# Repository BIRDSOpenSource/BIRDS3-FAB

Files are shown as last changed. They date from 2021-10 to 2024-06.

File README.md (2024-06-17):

<p align="center">
<a href="https://lean-sat.org/opensource/" class="button icon calendar">Join Monthly Webinar</a>
</p>

<div align="center">

</div>

# BIRDS3-FAB
 Documentation for the Foward Access Board used in the BIRDS 3 Satellite

## About the BIRDS3 Program:



The project was led by Kyushu Institute of Technology in Japan and involves students from Sri Lanka, Bhutan, Nepal and Japan.
Satellite Names: NepaliSat-1 (Nepal), Raavana-1 (Sri Lanka) and Ugiusu (Japan)

Stakeholders: Nepal Academy of Science and Technology (NAST) for Nepal, Arthur C Clarke Institute for Modern Technologies (ACCIMT) for Sri Lanka, and Kyushu Institute of Technology (Kyutech) for Japan.

Project duration: 2018-2020

CubeSat: 1U (10x10x10) cm3

Weight: 1.13kg

Launch Date: 17th April 2019

BIRDS-3 has 4 main missions in total; LoRa Demonstration Mission (LDM), Imaging Mission (CAM), Attitude Determination and Control Mission (ADCS) and Software Configurable Backplane Mission (BPB) 

## Organisation structure

## Features

## I like this project, can I help you?
You are welcome 🙂

* Give us a star ⭐
* Watch repository to be notified about updates 👀
* If you will find some errors, report them in Issues 🐞
* Try Birds designs on some real computer and let us know how it worked in Discussions. 💬
* We would greatly appreciate if you would also tell others about this ecosystem, it helps us to improve BIRDS Open Source. Thank you!

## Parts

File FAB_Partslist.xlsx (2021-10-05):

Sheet: Birds3_FAB
BIRDS3 FAB ADC & Connectors Revised: Tuesday, January 16, 2018
B3_0001-1-6 Revision: 0.16
Item | Quantity | Reference | Part
Item | Quantity | Reference | Part | メーカー | 型番 | パッケージ | 動作温度 | 偏差 | 定格 | データシート
1 | 1 | CN301 | 2row-50pin pin socket | 本多通信工業 | LPC-50M2LG | 2.00mmピッチ50pin | -25℃～85℃ |  | 1A
2 | 1 | CN303 | CONN SOCKET 10 | JST | B10B-PASK-1 (LF) (SN) | 2.00mmピッチ10pin | -25℃～85℃ |  | 3A
3 | 1 | CN304 | CONN SOCKET 4 | JST | B04B-PASK-1 (LF) (SN) | 2.00mmピッチ4pin | -25℃～85℃ |  | 3A
4 | 1 | CN401 | CONN SOCKET 12 | 廣杉計器 | PSR-210154-12 | 2.00mmピッチ12pin ライトアングル | -40℃～105℃ |  | 2A
5 | 4 | C1,C4,C28,C33 | 10uF | 村田製作所 | GRM21BR71A106KE51L | 2012 | -55℃～125℃ | ±10% | 10V
6 | 1 | C2 | 1uF | 村田製作所 | GRM188R71C105KA12J | 1608 | -55℃～125℃ | ±10% | 16V
7 | 21 | C3,C5,C6,C12,C17,C18,C19, C20,C21,C22,C23,C24,C25, C26,C27,C29,C30,C31,C32, C41,C42 | 0.1uF | KEMET | C0603C104J4RACTU | 1608 | -55℃～125℃ | ±5% | 16V
8 | 1 | C7 | 4700pF | TDK | C1608C0G1E472J080AA |  | -55℃～125℃ | ±5% | 25V
9 | 1 | C8 | 620pF | 村田製作所 | GRM1885C1H621JA01D | 1608 | -55°C～125°C | ±5% | 100V
10 | 2 | C11,C40 | 4.7uF | 村田製作所 | GRM188C71A475KE11D | 1608 | -55℃～125℃ | ±10% | 10V
11 | 6 | C9,C10,C13,C14,C15,C16 | 100uF | 村田製作所 | GRM32EC70J107ME15L | 3225 | -55℃～125℃ | ±20% | 6.3V
12 | 1 | C36 | 22uF | 村田製作所 | GRM21BD71A226ME44L | 2012 | -55℃～125℃ | ±20% | 10V
13 | 1 | D1 | DFLS2100 | DIODES | DFLS2100Q-7 | PowerDI123 | -55℃～175℃ |  | 2A
14 | 1 | D2 | BAS40-05W | NXP | BAS40-05W | 2.2x1.35 | -65℃～150℃
15 | 1 | J1 | Socket 4x2 | Samtec | SFMC-104-01-S-D | 1.27mm | -55℃ ～ 125℃
16 | 3 | J2,J4,J5 | Socket 2x2 | Samtec | SFMC-102-01-S-D | 1.27mm | -55℃ ～ 125℃
17 | 1 | J3 | Socket 5x2 | Samtec | SFMC-105-01-S-D | 1.27mm | -55℃ ～ 125℃
18 | 1 | J6 | CONN SOCKET 3x2/SM | Samtec | CLM-103-02-F-D | 1mm ピッチ | -55℃ ～ 125℃
19 | 6 | J7,J8,J13,J14,J15,J16 | JUMPER 2 | MAC8 | HWC-2P-G | 2mm SMT | －40～＋125℃ |  | 3A
20 | 2 | J9,J10 | pin header 2x2 | Amphenol FCI | 10112690-G03-02LF | 2mm SMT Right Angle | -55°C ~ 125°C |  | 2A | * RBF子基板
21 | 2 | J11,J12 | PHONOJACK STEREO-15 | CUI-inc | SJ1-2535-SMT |  | -25°C～85°C |  | 1A | * RBF子基板
22 | 1 | L1 | 3.3uH | Murata | FDVE1040-H-3R3M=P3 | 11.2mmx10mm | -20〜100℃ |  | 9A
23 | 8 | Q1,Q2,Q3,Q4,Q5,Q6,Q7,Q8 | SiA447DJ | Vishay | SiA447DJ-T1-GE3 | SC-70-6L | -55℃～150℃
24 | 2 | Q9,Q10 | DTR_PNP | Nexperia | PDTA144EU,115 | SOT-323-3
25 | 1 | Q11 | SSM6K411TU | TOSHIBA | SSM6K411TU | UF6 | -55℃～150℃
26 | 19 | R1,R2,R3,R23,R25,R28,R30, R33,R35,R37,R39,R49,R64, R67,R68,R74,R75,R76,R81 | 1K | KOA | RK73B1JTTD102J | 1608 | -55℃～155℃ | ±5% | 0.1W
27 | 15 | R4,R5,R6,R7,R8,R9,R10, R11,R53,R55,R58,R60,R61, R62,R63 | F10K | KOA | RK73H1JTTD1002F | 1608 | -55℃～155℃ | ±1% | 0.1W
28 | 5 | R12,R48,R54,R57,R85 | 10K | KOA | RK73B1JTTD103J | 1608 | -55℃～155℃ | ±5% | 0.1W
29 | 2 | R13,R17 | F100K | KOA | RK73H1JTTD1003F | 1608 | -55℃～155℃ | ±1% | 0.1W
30 | 1 | R14 | 7.5K | KOA | RK73H1JTTD7501F | 1608 | -55℃～155℃ | ±1% | 0.1W
31 | 1 | R15 | F105K | Yageo | RC0603FR-07105KL | 1608 | -55℃～155℃ | ±1% | 0.1W
32 | 1 | R16 | F64.9K | Yageo | RT0603BRD0764K9L | 1608 | -55℃～155℃ | ±1% | 0.1W
33 | 3 | R18,R51,R84 | NM1608 |  |  | 1608
34 | 2 | R19,R21 | F430K | KOA | RK73H1JTTD4303F | 1608 | -55℃～155℃ | ±1% | 0.1W
35 | 15 | R20,R22,R24,R26,R27,R29, R32,R34,R36,R38,R56,R78, R80,R82,R83 | 100K | KOA | RK73B1JTTD104J | 1608 | -55℃～155℃ | ±5% | 0.1W
36 | 6 | R31,R40,R47,R50,R52,R59 | F0.050 | Panasonic | ERJ-L03KF50MV | 1608 | -55℃～155℃ | ±1% | 0.2W
37 | 6 | R41,R42,R43,R44,R45,R46 | 100 | KOA | RK73B1JTTD101J | 1608 | -55℃～155℃ | ±5% | 0.1W
38 | 1 | R72 | F1.0 | Yageo | RC0603FR-071RL | 1608 | -55℃～155℃ | ±1% | 0.1W
39 | 2 | TH1,TH2 | 2x2_TH |  |  | RBF_SW子基板取り付け
40 | 1 | U1 | AD7298BCPZ | ANALOGDEVICES | AD7298BCPZ-RL7 | 20ピンLFCSP-WQ | -40～125℃
41 | 2 | U2.U28 | ACS722LLCTR-10AU | Allegro Microsystems | ACS722LLCTR-10AU | 8ピンSOIC | -40～150℃
42 | 1 | U3 | LTC3119EUFD | LTC3119EUFD#PBF | LINEARTECHNOLOGY | 28-QFN（4x5） | -40～125℃
43 | 6 | U4,U5,U6,U8,U13,U20 | LMP8640 | LMP8640MK-F/NOPB | Texas Instruments | 6ピンSOT | -40～125℃
44 | 2 | U7,U16 | SN74LVC1G125 | Texas Instruments | SN74LVC1G125DCKR | SC-70-5 | -40～125℃
45 | 1 | U9 | PIC16F1787 | MICROCHIP | PIC16F1787-E/MV | 40ピンUQFN | -40～125℃
46 | 2 | U10,U18 | LV8417CS-TE-L-H | ON Semiconductor | LV8417CS-TE-L-H | 9UFBGA | -20～85℃
47 | 2 | U11,U19 | G6K Relay | OMRON | G6KU-2F-Y-DC３ | 5.2 ｘ 6.5 x 10 | -40～70℃ |  | 3.3V
48 | 1 | U12 | ACS722LLCTR-05AB | Allegro Microsystems | ACS722LLCTR-05AB-T | 8ピンSOIC | -40～150℃
49 | 3 | U14,U17,U21 | UMD5N | ROHM | UMD5NTR | UMT6 | -55～150℃
50 | 1 | U15 | SN74CB3Q3305 | Texas Instruments | SN74CB3Q3305PWR | 8-TSSOP | -40～85℃
51 | 2 | U22,U27 | Si7106DN | Vishay Siliconix | SI7106DN-T1-E |  | -55～150℃
52 | 1 | U24 | LTC4361-2 | LINEARTECHNOLOGY | LTC4361IDC-2#TRMPBF | 8ピンDFN | -40～85℃
53 | 2 | U25,U26 | Si7232DN | Vishay Siliconix | SI7232DN-T1-GE3 | 1212-8 Dual | -55～150℃
54 | 1 | U30 | MCP6422-E/MS | Microchip | MCP6422-E/MS | 8LD MSOP | -40℃～125℃
他 | 数個 | ジャンパプラグ | JS-2 | MAC8

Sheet: 変更履歴
変更履歴
番号 | 日付 | 対象 | 内容 | 変更理由 | 変更者
0 | 2018-01-18 |  | 初版発行(rev0.15) |  | 吉田
0.16 | 2018-01-22 | U30,C42,R85 | 追加 | 入力バイアスをADレンジに合わせるため | 吉田
 |  | U28,C41,R84 | 追加 | I_RAW回路が無くなっていたため | 吉田
 |  | C8,R16 | 定数変更 | データシート計算式に合わせる | 吉田
 |  | R69 | 10K->100K | 330usec slow start | 吉田
 |  | R19,R21 | 定数変更 | 理想ダイオード無しにした為4.2Vに変更 | 吉田
0.17 | 2018-01-24 | J13,14 | 追加 | 要求による, | 吉田
 |  | J6 | 5ピン Molex ->1mm Samtec | 要求による. | 吉田
 |  | R65,R66,J15､J16 | R65,66削除しJ15に変更 | J13,14に伴いJumperにて変更で切りるように修正 | 吉田
 |  | CN303,304 | サイドエントリ→TOPエントリ | 要求による | 吉田
0.171 | 2018-02-05 | L2 | RLF7030T-4R7M3R4→CDRH3D28NP-4R7NC | 小型部品に変更（デモボードで再用品） | 吉田
0.18 | 2018-02-09 | U23,L2,R69,R70,R71,R73,R77, R79,C34,C35,C37,C38,C39 | 削除 | FAB3V3をUNREG1からDC-DC生成ではなく、3V3-1に変更 | 吉田
0.18 | 2018-02-09 | CN304 | B02B-PASK-1 (LF) (SN)-> B04B-PASK-1 (LF) (SN) | 誤記 | 吉田

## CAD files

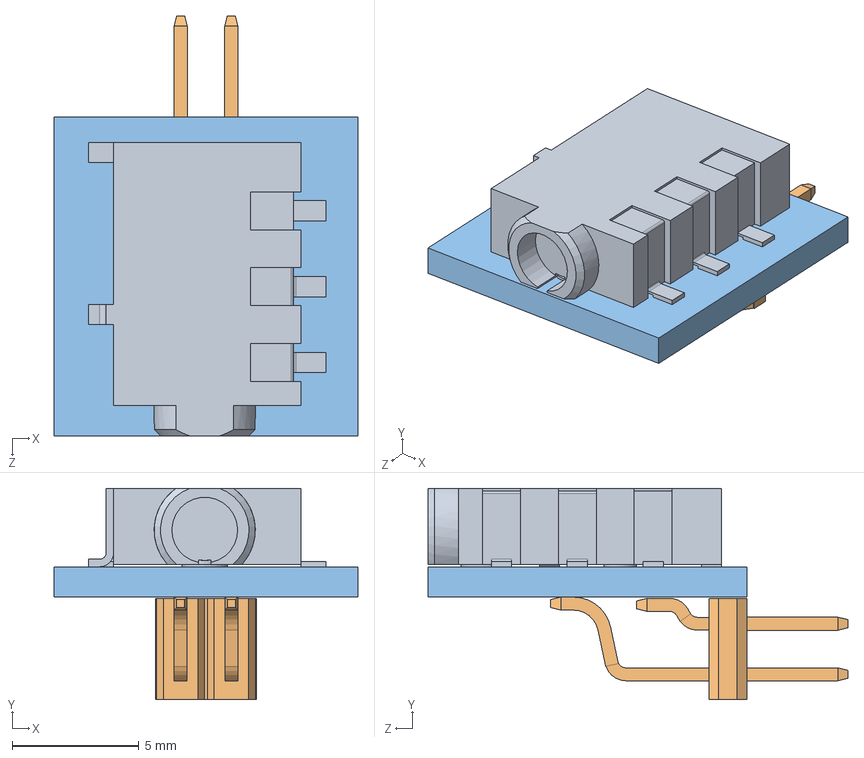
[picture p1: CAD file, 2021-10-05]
FAB_CAD/TH1.sldasm
12.0 x 8.35 x 16.6 mm
CUI_SJ1-2535-SMT
10112690-G03-02ULFc
Extruded_35

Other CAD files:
FAB_CAD/D1.sldasm
FAB_CAD/J14.sldasm
FAB_CAD/R58.sldasm
FAB_CAD/J4.sldasm
FAB_CAD/DCK0005A.sldasm
FAB_CAD/R19.sldasm
FAB_CAD/U19.sldasm
FAB_CAD/J7.sldasm
FAB_CAD/R18.sldasm
FAB_CAD/R11.sldasm
FAB_CAD/J8.sldasm
FAB_CAD/SFMC-105-01-S-D.sldasm
FAB_CAD/U27.sldasm
FAB_CAD/C11.sldasm
FAB_CAD/R46.sldasm
FAB_CAD/R31.sldasm
FAB_CAD/R74.sldasm
FAB_CAD/10112690-G03-02ULFc.sldprt
FAB_CAD/689248456.sldasm
FAB_CAD/689259200.sldasm
FAB_CAD/689259336.sldasm
FAB_CAD/689259472.sldasm
FAB_CAD/689259608.sldasm
FAB_CAD/689259744.sldasm
FAB_CAD/689259880.sldasm
FAB_CAD/689260016.sldasm
FAB_CAD/689260152.sldasm
FAB_CAD/689260288.sldasm
FAB_CAD/689260424.sldasm
FAB_CAD/689260560.sldasm
FAB_CAD/689260696.sldasm
FAB_CAD/689260832.sldasm
FAB_CAD/689260968.sldasm
FAB_CAD/689261104.sldasm
FAB_CAD/689261240.sldasm
FAB_CAD/689261376.sldasm
FAB_CAD/689261512.sldasm
FAB_CAD/689261648.sldasm
FAB_CAD/689261784.sldasm
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

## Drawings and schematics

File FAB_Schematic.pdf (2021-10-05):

# Front Access Window

## 2 V0.20 2018/05/23 U1 AD7298 -> AD7490, V1-V6 INPUTassign, MISC changes relatating

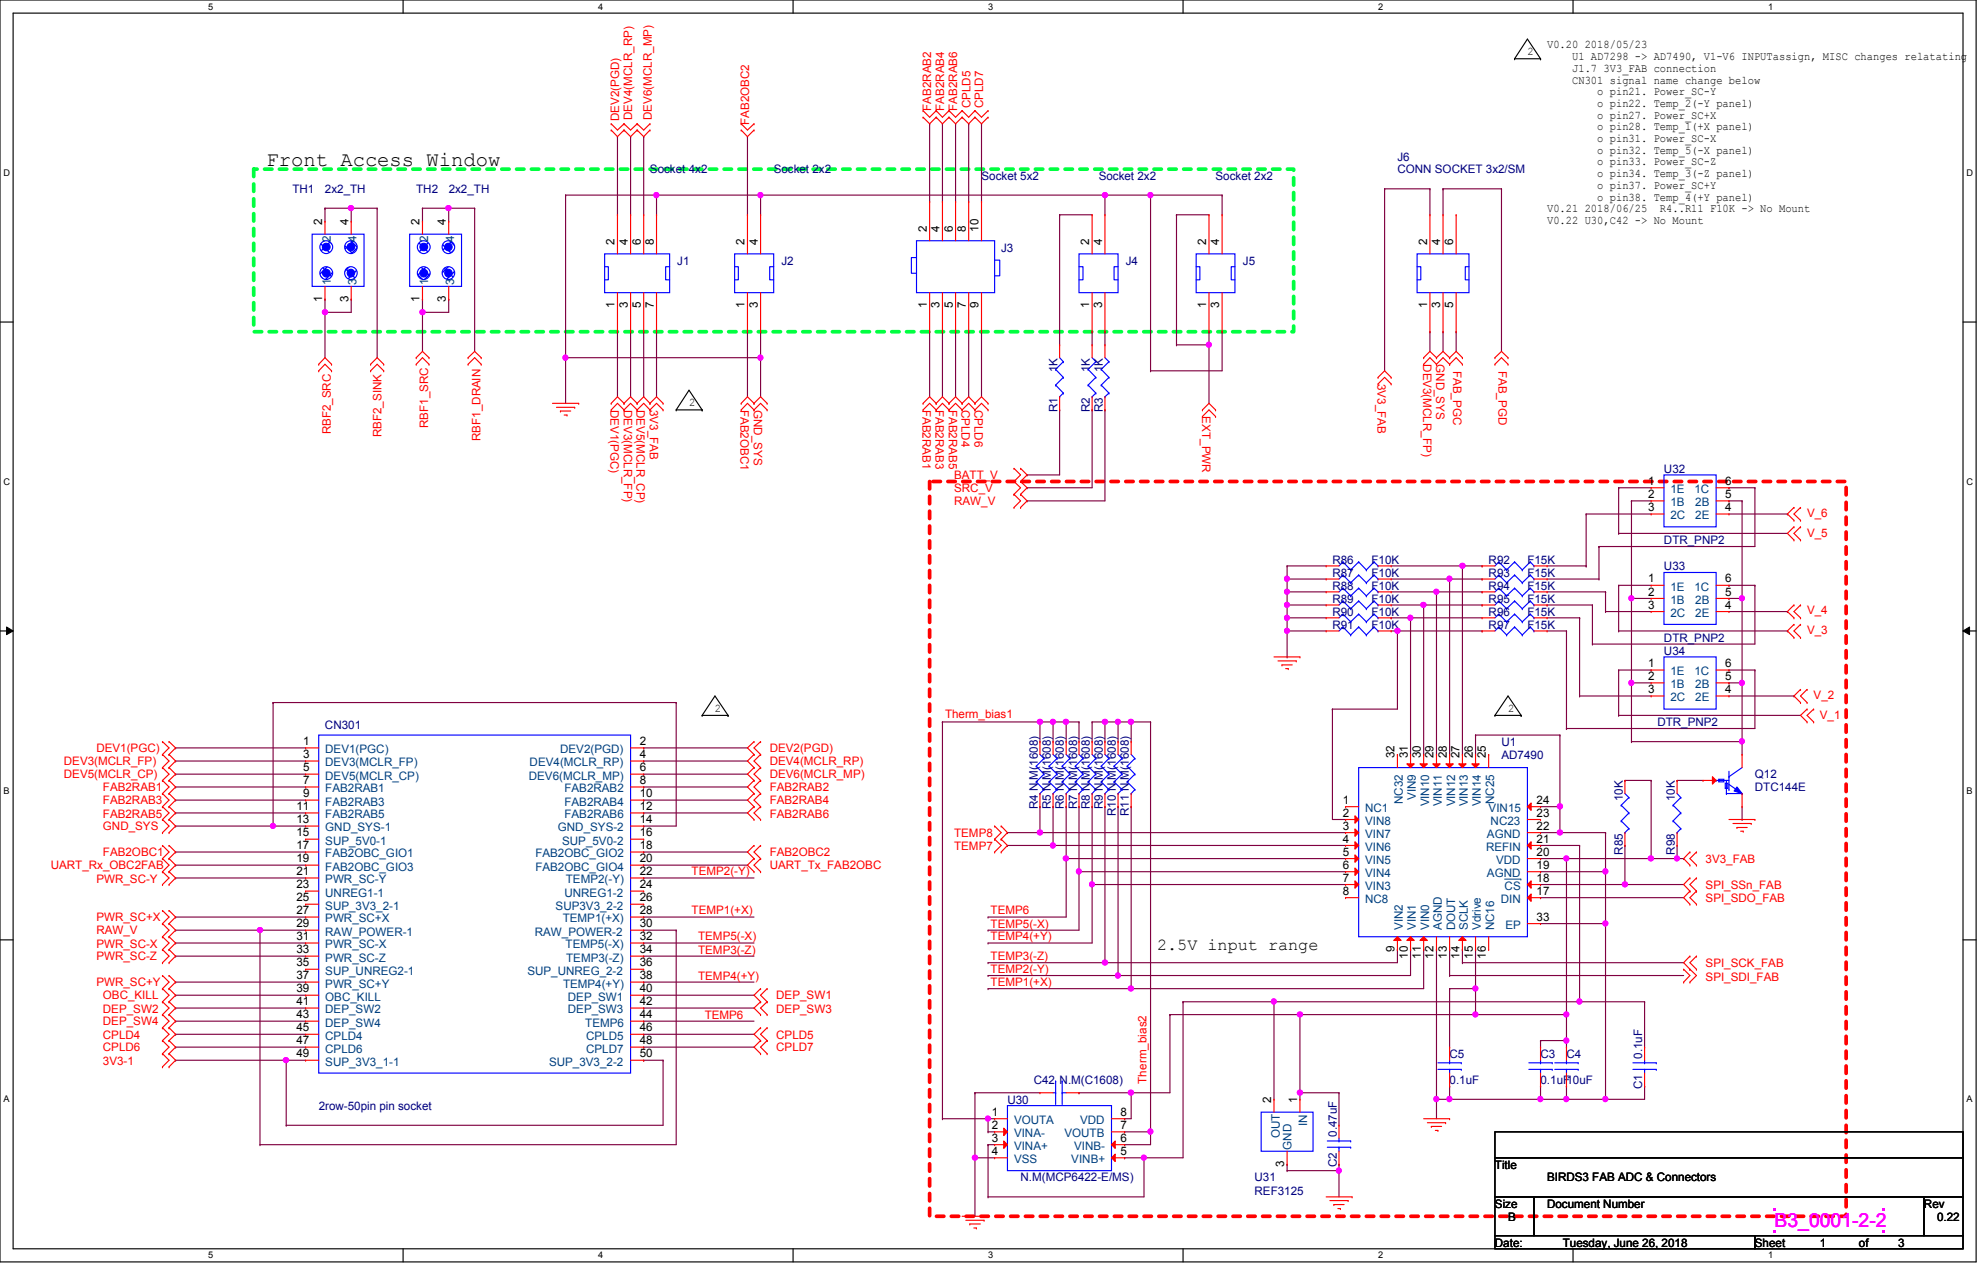
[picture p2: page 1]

U33 1E 1 2C 3 2E 4 2B 5 1C 6 1B 2 DTR_PNP2

U34 1E 1 2C 3 2E 4 2B 5 1C 6 1B 2 DTR_PNP2

Kill switch | Deployment SW1 | RBF1
Deployment SW2 | Deployment SW3

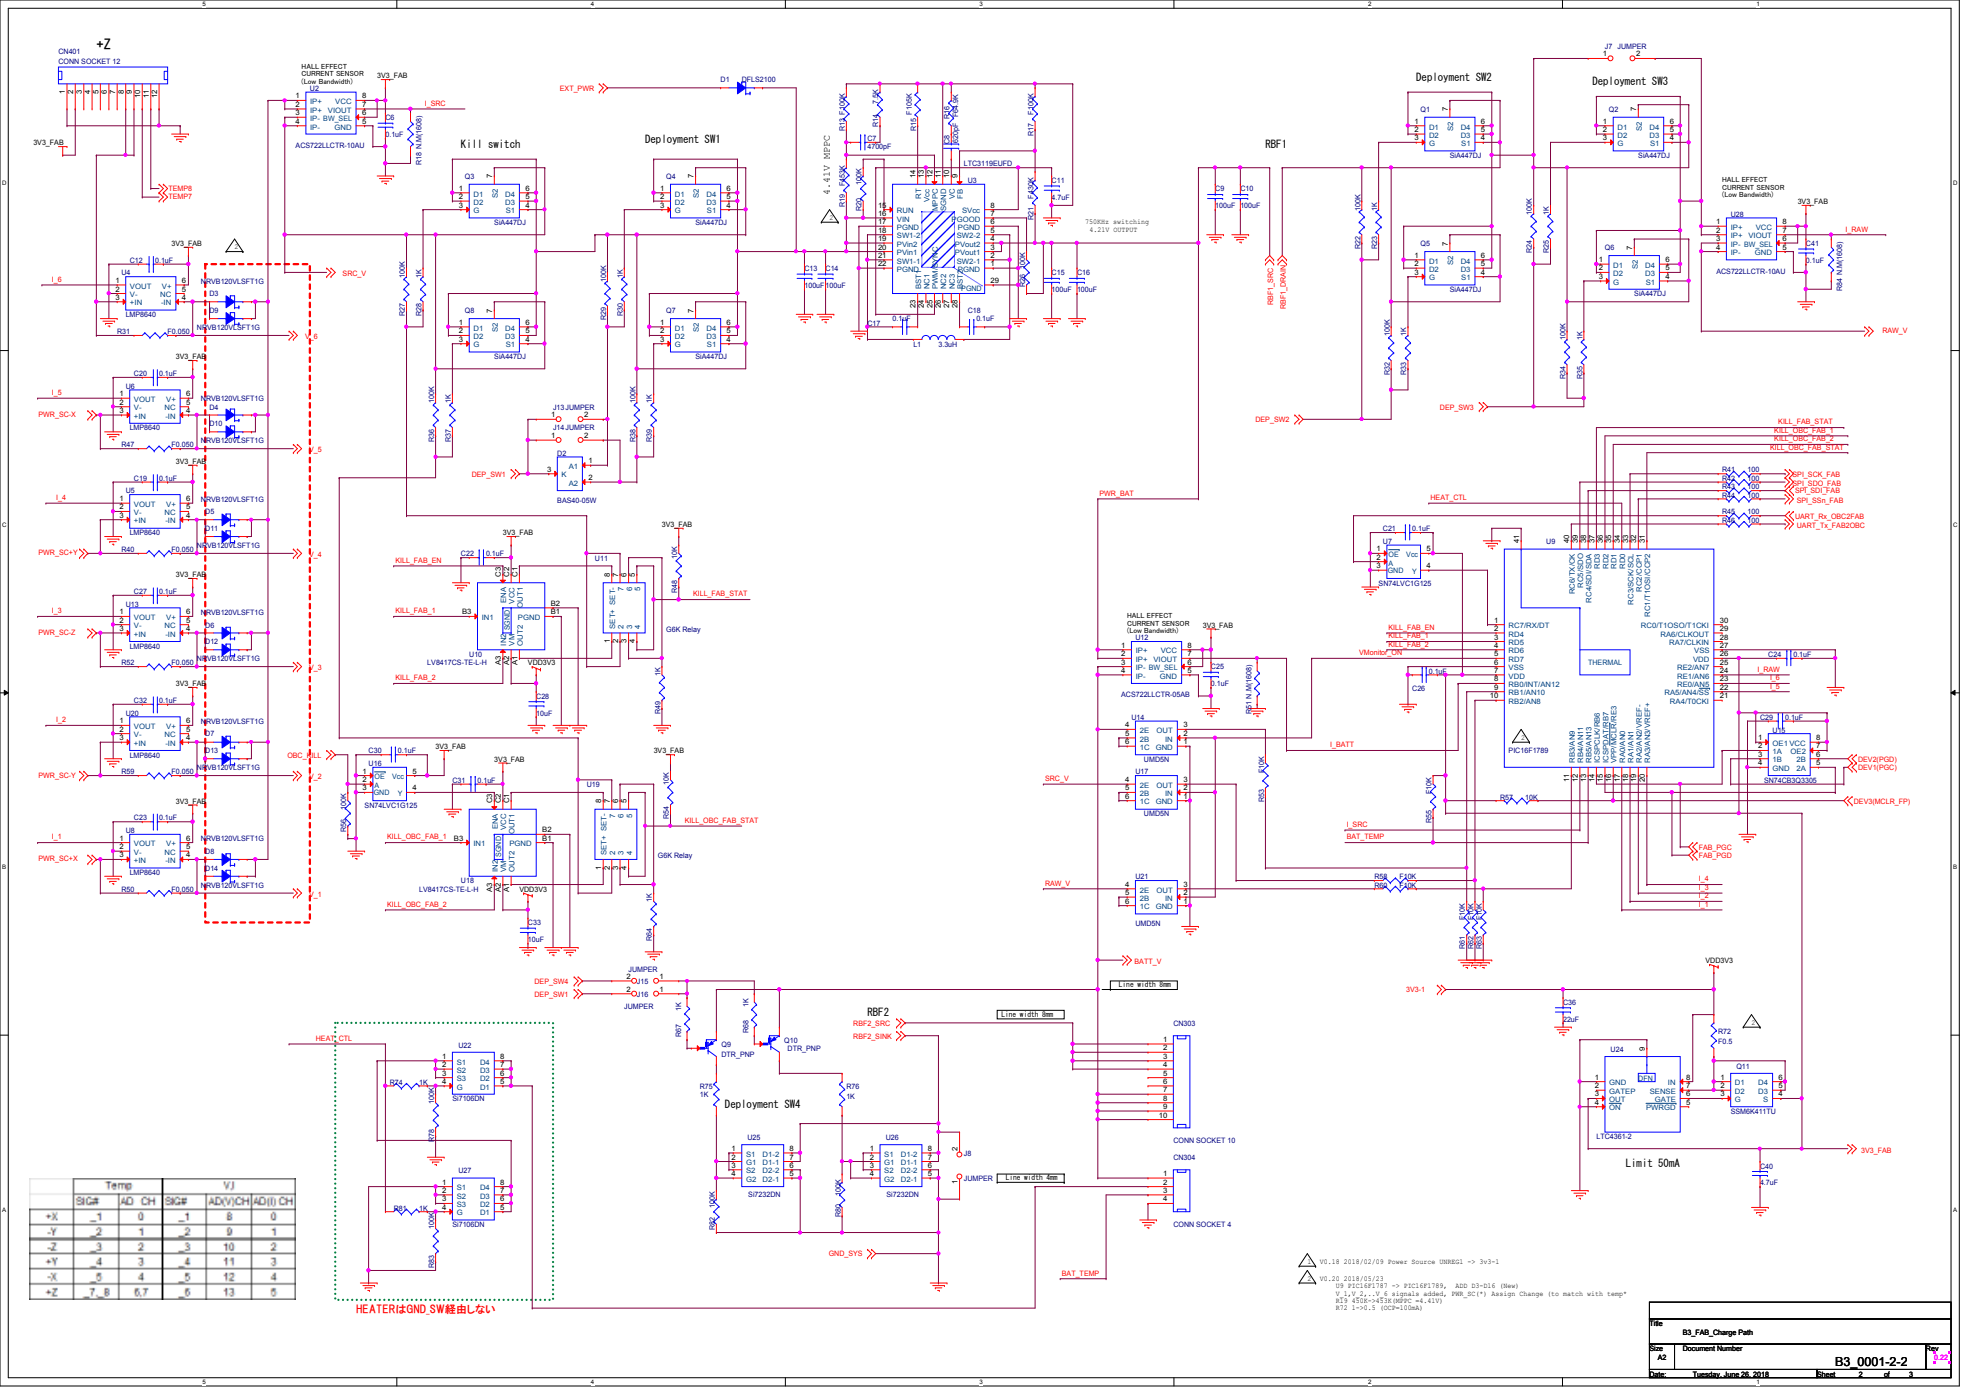
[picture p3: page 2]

U9 PIC16F1787 -> PIC16F1789, ADD D3-D16 (New)
V_1,V_2,..V_6 signals added, PWR_SC(*) Assign Change (to match with temp*
R19 450K->453K(MPPC =4.41V)
R72 1->0.5 (OCP=100mA)

D | D

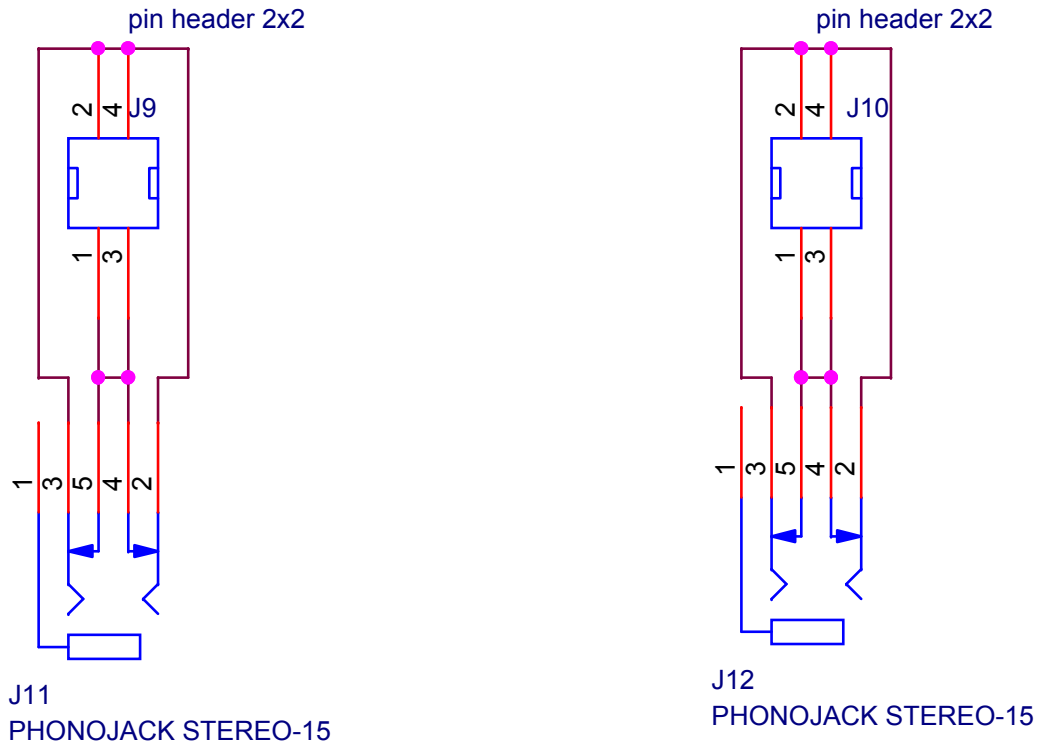
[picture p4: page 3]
Title; Size; Document Number; Rev; Date:; Sheet; RBF switch; Tuesday, June 26, 2018; pin header 2x2; J11 PHONOJACK STEREO-15; J12 PHONOJACK STEREO-15

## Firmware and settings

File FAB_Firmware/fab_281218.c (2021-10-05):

#include <16F1789.h>
#device ADC=12;
#fuses WDT,NOMCLR
#use delay(internal=16MHz)
#include <PIC16F1789_registers.h>
#include <define_func.c>

//#use rs232(baud=9600,parity=N,xmit=PIN_B7,rcv=PIN_B6,bits=8,stream=PORT1)
#use rs232(UART1,baud=9600,parity=N,bits=8,stream=MPIC)


#use spi(MASTER, CLK = PIN_C3, DI = PIN_C4, DO = PIN_C5,ENABLE = PIN_C2, BAUD = 9600, BITS = 16, STREAM = PORT2, MODE = 2 )

int8 fabData[39] = {0};
unsigned int16 SRC_current = 0;
unsigned int32 bat_current = 0;

#include <ADC_reading_func.c>

BYTE rx_chars[8] = {0};

#int_rda
void serial_isr(){
 
  rx_chars[0] = fgetc(MPIC);
} 

void main()
{
  
   fabData[0] = 0x33;
   //RD0 = 1;
   //fabData[37] = 1;
  
   TRISD7 = 0; LATD7 = 1; //enabling buffer for voltage measurements
   
   TRISD0 = 0; RD0 = 0; //disabling battery heater
   
   check=read_eeprom(check_memory);
   kill_flag = read_eeprom(memory);
   
//!   kill_fab_forward(); //kill switch forward mode
//!   kill_OBC_forward();  

   if ((check!=8)&&(kill_flag!=5))
      {
        kill_fab_forward(); //kill switch forward mode
        kill_OBC_forward(); //kill switch OBC forward mode
      }
   else
      {     
        kill_fab_reverse(); //kill switch reverse mode
        kill_OBC_reverse(); //kill switch OBC reverse mode
      }
      
   
    SETUP_ADC(ADC_CLOCK_INTERNAL);
    SETUP_ADC_PORTS(ALL_ANALOG);  //setting all analog ports
   
    enable_interrupts(INT_RDA);
    enable_interrupts(global);   
    
    
   while(True)
   
   {     
         battery_heater();
         kill_status();

         if(rx_chars[0] == 0x61)//receiving sensor data request interrupt
         {             
           temperature();
           voltages();
           adc_FAB();
           
           rx_chars[0]=0;
            
           delay_ms(10);
                
           for (int i=0;i<39;i++)
           {
                  fputc(fabData[i],MPIC);                              
           }
         
          }
         
         
         else if(rx_chars[0] == 0x17){            //receiving Kill switch interrupt
            
            rx_chars[0]=0;
            
            delay_ms(10);
            
            kill_fab_reverse();
            kill_OBC_reverse();
            
            write_eeprom(check_memory,8);
            check=8;
            write_eeprom(memory,5);
            kill_flag=5;
            
         }
         
         else if(rx_chars[0] == 0x18){            //receiving Kill switch interrupt
            
            rx_chars[0]=0;
            
            delay_ms(10);
            
            kill_fab_forward();
            kill_OBC_forward();
            
            write_eeprom(check_memory,1);
            check=1;
            write_eeprom(memory,1);
            kill_flag=1;
            
         }
                               
  }   
}
  

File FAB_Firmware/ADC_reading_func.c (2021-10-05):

//________________________READ VOLTAGE CHANNELS OF ADC_______________________________________________________________________________________//

unsigned int16 READ_vol_CHANNEL(int16 Address)
{
  
    RC2 = 0;
    
    spi_xfer(PORT2, Address);
                
    unsigned int16 vol_X = spi_xfer(PORT2);
         
    unsigned int16 adc_res16 = vol_X & 0x0FFF; //removing the address bits
                                
    RC2 = 1;
      
    delay_us(20);
    
    return adc_res16;
}

//________________________READ TEMPERATURE CHANNEL OF ADC_________________________________________________________________________________________________________//


int16 READ_temp_CHANNEL(int16 Address)
{
  
   // RC2 = 0;
                      
   spi_xfer(PORT2, Address);
   
   unsigned int16 temp_X = spi_xfer(PORT2);
    
   unsigned int16 adc_temp16 = temp_X & 0x0FFF; //removing address bits
               
    //RC2 = 1;
    
    delay_us(20);
    
    return adc_temp16;
}
//________________________CALIBRATE TEMPERATURE CHANNEL OF ADC_________________________________________________________________________________________________________//

void temperature(void) {
                  
         
          temp_pX = READ_temp_CHANNEL(pX_temp);
          
          fabData[1] = (temp_pX >> 8) & 0xFF;
          fabData[2] = temp_pX & 0x00FF;                                      
    //-------------------------------------------------------//      
          temp_mY = READ_temp_CHANNEL(mY_temp);
          
          fabData[3] = (temp_mY >> 8) & 0xFF;
          fabData[4] = temp_mY & 0x00FF;       
     //-------------------------------------------------------//       
          temp_mZ = READ_temp_CHANNEL(mZ_temp);
          
          fabData[5] = (temp_mZ >> 8) & 0xFF;
          fabData[6] = temp_mZ & 0x00FF;       
    //-------------------------------------------------------//     
          temp_pY = READ_temp_CHANNEL(pY_temp);
          
          fabData[7] = (temp_pY >> 8) & 0xFF;
          fabData[8] = temp_pY & 0x00FF;       

    //-------------------------------------------------------//              
//!          temp_mX = READ_temp_CHANNEL(mX_temp);
//!          
//!          fabData[9] = (temp_mX >> 8) & 0xFF;
//!          fabData[10] = temp_mX & 0x00FF;       
    //-------------------------------------------------------//         
          temp_CPLD = READ_temp_CHANNEL(CPLD_temp);
          
          fabData[9] = (temp_CPLD >> 8) & 0xFF;
          fabData[10] = temp_CPLD & 0x00FF;       
    //-------------------------------------------------------//         
//!          temp_pZ1 = READ_temp_CHANNEL(pZ_temp1);
//!          
//!          fabData[13] = (temp_pZ1 >> 8) & 0xFF;
//!          fabData[14] = temp_pZ1 & 0x00FF;       

    //-------------------------------------------------------//         
          temp_pZ2 = READ_temp_CHANNEL(pZ_temp2);
          
          fabData[11] = (temp_pZ2 >> 8) & 0xFF;
          fabData[12] = temp_pZ2 & 0x00FF;  
          
          return;
}

//________________________CALIBRATE VOLTAGE CHANNEL OF ADC_________________________________________________________________________________________________________//

void voltages(void) {

          vol_pX = READ_vol_CHANNEL(pX_vol);
          
          fabData[13] = (vol_pX >> 8) & 0xFF;
          fabData[14] = vol_pX & 0x00FF;                             
    //-------------------------------------------------------//   
          vol_mY = READ_vol_CHANNEL(mY_vol);
          
          fabData[15] = (vol_mY >> 8) & 0xFF;
          fabData[16] = vol_mY & 0x00FF;       
     //-------------------------------------------------------//       
          vol_mZ = READ_vol_CHANNEL(mZ_vol);
          
          fabData[17] = (vol_mZ >> 8) & 0xFF;
          fabData[18] = vol_mZ & 0x00FF;       
          
    //-------------------------------------------------------//     
          vol_pY = READ_vol_CHANNEL(pY_vol);
          
          fabData[19] = (vol_pY >> 8) & 0xFF;
          fabData[20] = vol_pY & 0x00FF;       
                    
    //-------------------------------------------------------//      
//!          vol_mX = READ_vol_CHANNEL(mX_vol);
//!          
//!          fabData[25] = (vol_mX >> 8) & 0xFF;
//!          fabData[26] = vol_mX & 0x00FF;       
//!
    //-------------------------------------------------------//         
          vol_pZ = READ_vol_CHANNEL(pZ_vol);
          
          fabData[21] = (vol_pZ >> 8) & 0xFF;
          fabData[22] = vol_pZ & 0x00FF;     
          
          return;
}

//________________________READ ADC CHANNEL OF FAB CURRENT_________________________________________________________________________________________________________//

int8 READ_PIC_ADC(int8 port_name)
{
   SET_ADC_CHANNEL(port_name); //  routing nth channel to adc
   delay_us(20);
   unsigned int16 ADC_VALUE = READ_ADC();   
   
   int8 bit8value = ADC_VALUE/16;
   
   return bit8value;
}

//=================================16bit value reading ADC===================================//

int16 READ_PIC_ADC16(int8 port_name)
{
   SET_ADC_CHANNEL(port_name); //  routing nth channel to adc
   delay_us(20);
   unsigned int16 ADC_VALUE16 = READ_ADC();   
     
   return ADC_VALUE16;
}

//________________________CREATE ARRAY OF FAB DATA_________________________________________________________________________________________________________//

void adc_FAB(void)
{

        fabData[23] = READ_PIC_ADC(0);         //I out plus X 
             
        fabData[24] = READ_PIC_ADC(1);         //I out minus Y

        fabData[25] = READ_PIC_ADC(2);         //I out minus Z 
      
        fabData[26] = READ_PIC_ADC(3);         //I out plus Y

        fabData[27] = READ_PIC_ADC(5);         //I out plus Z
 
        fabData[28] = READ_PIC_ADC(6);         // I_raw

        fabData[29] = READ_PIC_ADC(8);       // SRC_voltage

        fabData[30] = READ_PIC_ADC(9);         //Raw_voltage
        
 //============================ reading the SRC current ==================================// 
       
       for(int k=0; k<100; k++)
       {
       SET_ADC_CHANNEL(11); //  routing nth channel to adc
       delay_us(10);
        SRC_current = SRC_current + READ_ADC(); 
        delay_ms(1);
        }
        
       SRC_current= SRC_current/100;
       
       fabData[31] = (SRC_current >> 8)& 0xff;
       fabData[32] = SRC_current & 0x00ff;
       
       SRC_current = 0;
       
//==================================end of reading SRC Current==============================//
      
        fabData[33] = READ_PIC_ADC(10);  //battery voltage
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
